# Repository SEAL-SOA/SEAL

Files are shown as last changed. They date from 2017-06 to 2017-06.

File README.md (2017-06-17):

# SEAL
Sistema Embebido para Analisis de Lluvia
El sistema consiste en medir turbiedad y nivel de agua en un tanque, y analizando la calidad del agua, determinar si el agua se destina a riego o a consumo.
Adicionalmente cuenta con una aplicación en Android que lee los valores que envia Arduino por Bluetooth y permite tomar el control de las bombas de agua.

Desarrollado por alumnos de la Universidad Nacional de la Matanza

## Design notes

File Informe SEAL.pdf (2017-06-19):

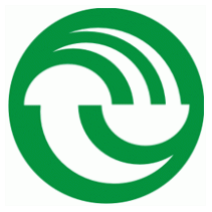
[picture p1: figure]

# UNLaM

# Departamento de Ingeniería e Investigaciones Tecnológicas

# Sistemas Operativos Avanzados

## Internet of Things

## Sistemas Embebidos + Android

# “Sistema Embebido de Análisis de Lluvia”

# SEAL

## 1er cuatrimestre – Año 2017

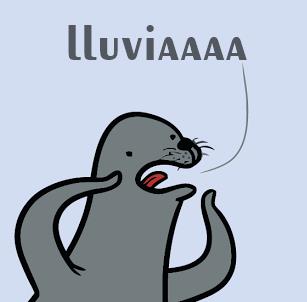
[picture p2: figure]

## Integrantes:

### Coria, Santiago Greco, Maximiliano Minardi, Matías Piemontese, Gerardo

Fecha | Versión | Devolución
19/6/2017 | 1.0

SEAL – Sistema Embebido de Análisis de Lluvia

## Contenido

## 1. Objetivos del Trabajo Práctico

Desarrollar los conocimientos y experiencias adoptados en la cursada acerca de Sistemas Embebidos, IoT y Android con el fin de implementar un sistema capaz de medir la turbiedad del agua de lluvia y determinar en base a las partículas suspendidas en el agua, si la misma es apta para consumo o es destinada para riego.

## 1. Entorno de Trabajo

## 1.1 Hardware

### 1.1.1 Sistema Embebido

- Notebook Lenovo G580 (Intel Core i5 – 4 GB RAM – Windows 10)
- Arduino Mega 2560
- Cables para la conexión entre placa y sensores
- 1 x Placa de desarrollo
- 1 x Sensor digital de temperatura sumergible DS18B20
- 1 x Sensor digital de ultrasonido HC-SR04
- 1 x Sensor analógico/digital de turbidez DFSEN0189 (usamos el
| modo analógico)
- 1 x LCD Module 20x4
- 1 x Interfaz I2C/SPI para LCD
- 1 x Resistencia 1/4W 4K7 Ohm para sensor de temperatura
- 1 x Módulo bluetooth HC-06
- 1 x Módulo de 2 relés de 5v EARE00102SL
- 2 x Bombas de agua

### 1.1.2 Aplicación Android

- DELL Inspiron (Intel Core i7 -16 GB RAM – Windows 10)
- LG 4 PLUS – Android 6.0.1
- Sensor Acelerómetro
- Sensor de Luz
- Vibrador del dispositivo

## 1.2 Software 1.2.1 Sistema Embebido

- Arduino IDE 1.8.2
- Windows 10 Home Single Language x64

## 1.2.2 Aplicación Android

- Android Studio versión 2.3.2

## 2. Alcance del Sistema

## 2.1 Sistema Embebido

2.1.1 | El sistema embebido debe realizar las siguientes
| mediciones: ▪ Turbiedad del agua en base a las partículas suspendidas ▪ Temperatura del agua ▪ Nivel/Volumen de agua en litros.
2.1.2 | El sistema embebido debe enviar constantemente las
| mediciones realizadas por medio de la conexión bluetooth hacia la aplicación Android y también mostrar dichos valores en la pantalla LCD.
2.1.3 | El sistema embebido debe contemplar niveles máximos
| y mínimos de agua para que el nivel de agua no supere el máximo de 3,8 litros ni sea menor a 1,2 litros y el agua quede por debajo de las bombas de drenaje.
2.1.4 | El sistema embebido debe analizar la turbiedad del
| agua cuando el nivel de la misma supere 3,8 litros.
2.1.5 | El sistema debe realizar el drenaje del agua luego de
| analizar la turbiedad de la misma hasta llegar a un nivel tope de 1,2 litros.
2.1.6 | El sistema embebido debe decidir qué bomba encender
| en base a la turbiedad del agua. Si la turbiedad es menor o igual a 2 NTU se debe encender la bomba correspondiente a “Agua para Consumo”. Si la turbiedad es mayor a 2 NTU se debe encender la bomba correspondiente a “Agua para Riego”.
2.1.7 | El sistema embebido debe enviar constantemente, la
| información obtenida por medio de los sensores, a la aplicación por medio de una conexión bluetooth.
2.1.8 | El sistema embebido debe reaccionar ante las
| instrucciones enviadas por medio de la aplicación.
2.1.9 | El sistema embebido debe admitir dos modos de
| operación (automático y manual) determinado por el usuario de la aplicación.

### 2.1.10 El sistema embebido debe hacer parpadear el display

| LCD al momento de recibir una señal especifica de la aplicación Android.

## 2.2 Aplicación Android

2.2.1 | La aplicación Android debe recibir los valores enviado
| por el sistema embebido, de temperatura, turbiedad y ultrasonido por medio de una conexión bluetooth y mostrarlo constantemente por medio de la interfaz.
2.2.2 | La aplicación Android debe permitir cambiar el modo
| de operación del sistema embebido pudiendo elegir entre el modo manual y el modo automático.

### - Modo Automático: El sistema embebido lee

| constantemente el nivel de agua. Al llegar a la cantidad de 3,8 litros, el sistema embebido analiza la turbiedad y decide si destina el agua a riego o a consumo abriendo una u otra bomba, pudiendo así drenar el tanque principal hasta un nivel mínimo de 1.2 litros para no quedar por debajo de las bombas de drenaje.

### - Modo Manual: Al estar en modo manual, el drenaje

| de las bombas se realizará en base a lo que seleccione el usuario por medio de la aplicación. El mismo tendrá la opción de abrir la bomba destinada a agua para consumo o aquella destinada para riego independientemente de la turbiedad del agua. Si bien el control será manual el sistema tendrá un corte automático para que el agua no quede en un nivel por debajo de las bombas y dañe el sistema.
2.2.3 | La aplicación Android debe implementar el sensor
| acelerómetro para determinar qué bomba se debe encender en base a la inclinación hacia la izquierda (bomba de riego) o derecha (bomba de consumo) del dispositivo.
2.2.4 | La aplicación Android debe accionar el vibrador del
| dispositivo en caso que se accione una u otra bomba de drenaje y el modo de operación sea manual.
2.2.5 | La aplicación Android debe enviar una señal al sistema
| embebido cuando detecte un nivel de luz menor al 3 lumenes.

## 3. Diagrama General del Sistema

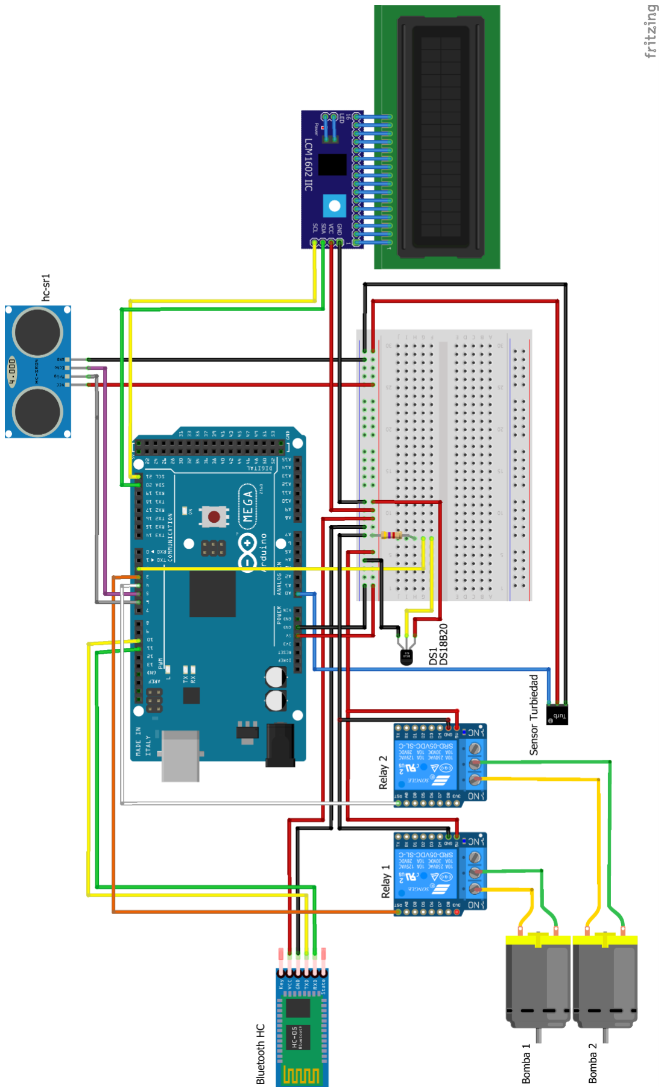
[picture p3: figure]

### El sensor principal de nuestro proyecto es el sensor de TURBIEDAD el

cual posee un switch para cambiar de modo analógico a digital o viceversa.

### Este sensor utiliza la luz para detectar partículas en suspensión en el agua

### mediante la medición de la transmitancia de luz y la velocidad, que cambia con la cantidad de sólidos suspendidos totales (SST) en el agua. A medida

que aumenta el SST, aumenta el nivel de turbidez.

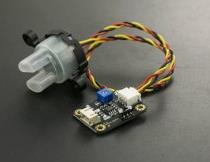
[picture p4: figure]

### Luego en base a las SST devueltos el sensor devuelve un valor que varia entre 0 a 1023. Se debe calcular el voltaje correspondiente a dicha medición mediante la siguiente fórmula:

### Voltaje = SST x (

5.0
1024)

### Una vez obtenido el voltaje se calcula los NTU (Unidad Nefelometrica de Turbidez) equivalentes mediante la siguiente fórmula:

### NTU = −1120.4 x Voltaje + 5742.3 x Voltaje − 4352.9

Si bien esa es la forma que indica el fabricante para calcular los NTU del agua, cuando realizamos las pruebas del sensor, obtuvimos valores fuera de dichos márgenes. Sumado a esto, las mediciones tomadas se veían afectadas a condiciones externas como por ejemplo la luz ambiental. Por lo cual, decidimos adaptar dicho sensor para que se vea afectado lo mínimo posible por estas condiciones colocándole un capuchón que disminuya la

incidencia de la luz.

### Luego de estas modificaciones, realizamos nuevas mediciones y adoptamos el siguiente criterio para obtener los valores de turbiedad en NTU:

Valor informado por el Sensor (VS) | Valor correspondiente a NTU | Informe del Agua
VS >= 780 | 1 | Apta para consumo
760 <= VS < 780 | 1.5 | Apta para consumo
745 <= VS < 760 | 2 | Apta para consumo
VS < 745 | -(166/15) x VS + (24740/3) | Disponible para Riego

## 4. Implementación

## 4.1 Sistema Embebido

4.1.1 Display LCD Para la implementación del LCD se deben agregar las librerías Wire.h y LiquidCrystal_I2C.h para la utilización de la interfaz

I2C. Una vez realizado esto declaramos los parámetros de escritura del LCD de la siguiente manera: LiquidCrystal_I2C lcd(0x27,20,4);
Finalmente inicializamos el LCD y encendemos el backlight mediante las funciones lcd.init() y lcd.backlight().
De esta manera el LCD queda disponible para escribir por pantalla mediante las funciones lcd.setCursor() y lcd.print()

4.1.2 Sensor de temperatura sumergible Para la implementación del sensor de temperatura se deben agregar las librerías OneWire.h y DallasTemperature.h. Luego debemos declarar el PIN utilizado para dicho sensor (nosotros utilizamos el pin digital 2) y finalmente declaramos el bus para la comunicación OneWire, instanciamos la biblioteca DallasTemperature e inicializamos el sensor mediante le siguiente código: OneWire ourWire(pinTemp); DallasTemperature sensorTempSumerg(&ourWire); sensorTempSumerg.begin(); Finalmente obtenemos el valor de la temperatura mediante las siguientes llamadas a funciones: sensorTempSumerg.requestTemperatures(); sensorTempSumerg.getTempCByIndex(0);

## 4.1.3 Sensor de Ultrasonido

Para la implementación del sensor de ultrasonido no se necesitan agregar librerías. Sólo se deben declarar los pines ECHO y TRIGGER. El pin ECHO de entrada determina el tiempo de rebote del ultrasonido y el pin TRIGGER de salida determina el pulso ultrasónico (nosotros utilizamos los pines 5 y 6): pinMode(trigPin,OUTPUT);
pinMode(echoPin,INPUT);

Finalmente calculamos la distancia de la siguiente forma:

digitalWrite(trigPin, LOW);/*Estabilización del sensor*/ delayMicroseconds(2);
digitalWrite(trigPin, HIGH); /*Envío del pulso ultrasónico*/ delayMicroseconds(10);
digitalWrite(trigPin, LOW);
duracion = pulseIn(echoPin,HIGH);/* Función para medir la longitud del pulso entrante. Mide el tiempo que transcurrido entre el
envío del pulso ultrasónico y cuando el sensor recibe el rebote */

distancia = (duracion/(float)2) / 29.1;
capacidad = -0.2656 * distancia + 4.7687;

## 4.1.4 Sensor de Turbiedad

Para la implementación del sensor de turbiedad tampoco es necesario agregar librerías. Simplemente se debe conectar el sensor a una de las entradas analógicas de la placa Arduino y realizar la lectura de dicho pin mediante la siguiente instrucción: int sensorValue = analogRead(A0);

## 4.1.5 Relays para bombas

Para la utilización de los relays no es necesaria incluir librerías, pero se debe declarar los pines utilizados para ambos relays:
int pinRelay1 = 3; | //RELAY 1
int pinRelay2 = 4; | //RELAY 2

Al inicio del proceso, apagamos ambos relays mediante las siguientes instrucciones:
digitalWrite(pinRelay1,HIGH);
digitalWrite(pinRelay2,HIGH);

Finalmente en el proceso se deben abrir y cerrar las bombas mediante las instrucciones digitalWrite(pinRelay,LOW); o digitalWrite(pinRelay, HIGH); respectivamente

## 4.2 Aplicación Android

Al iniciar, la aplicación Android solicita encender el Bluetooth del dispositivo en caso de que el mismo no se encuentre conectado.
En la primera pantalla, el usuario debe seleccionar el Bluetooth dentro de la lista de dispositivos vinculados.

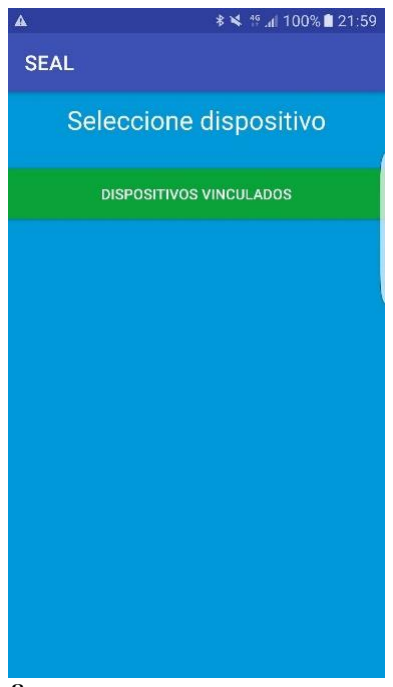
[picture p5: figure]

a

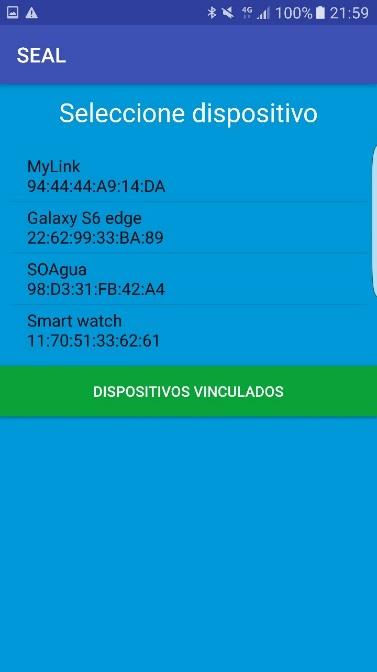
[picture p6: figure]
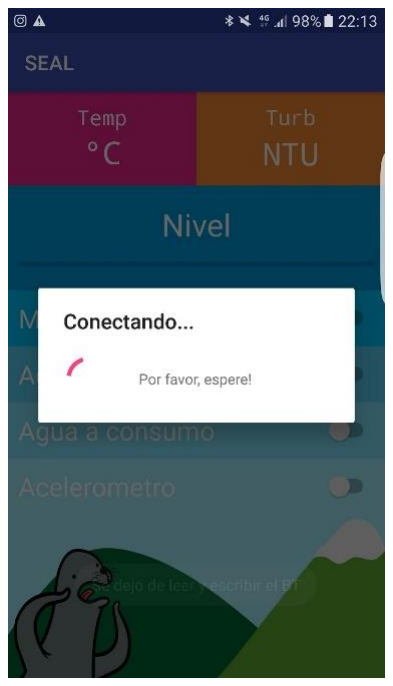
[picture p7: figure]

do, la aplicación Android redirecciona a la pantalla principal donde se visualizan los valores de temperatura, turbiedad y nivel de agua recibidos del sistema embebido. Además, da información sobre el modo de operación, los estados de las bombas de drenaje y la opción para habilitar la funcionalidad del acelerómetro.

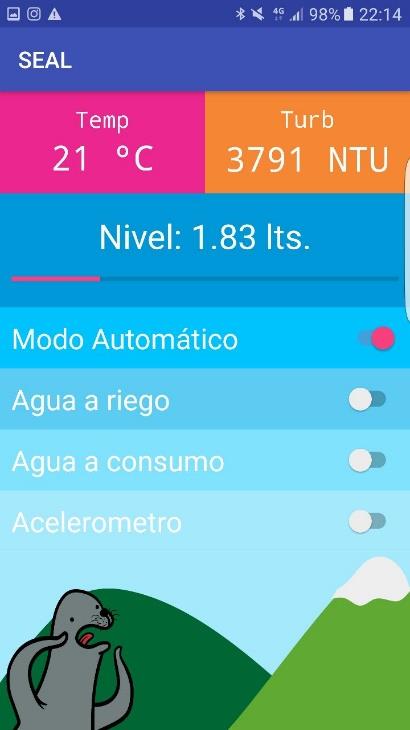
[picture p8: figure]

Al cambiar el modo de operación a Manual, el usuario puede activar las bombas de drenaje si el nivel de agua es superior a 1,2 lts. haciendo click en los switchs o habilitando el sensor acelerómetro y luego, desplazando el celular de izquierda a derecha.

En cambio, el modo de operación Automático, únicamente permite la visualización de los valores e impide al usuario activar las bombas.

## 5. Comunicación Bluetooth

## 5.1 Arduino a Android

Para la utilización del bluetooth se debe incluir la siguiente librería: #include <SoftwareSerial.h>
Luego declaramos los pines RX y TX donde conectamos el modulo HC-06 a la placa Arduino, con la siguiente instrucción:
SoftwareSerial BT(10,11);

Luego realizamos la lectura de los valores que enviamos desde el dispositivo Android mediante el siguiente Código: if(BT.available()) // Si llega un dato por el puerto BT se envía al monitor serial
{
msjin = LeerBT();
Serial.print(msjin);
if (msjin.equals("#FA~")){ArdCtl=1;} else if(msjin.equals("#FM~")){ArdCtl=0;} }

Donde LeerBt() es:
String LeerBT(){
String msj;
delay(10); //delay de contingencia, para cargar el buffer //Cargo el buffer en una variable hasta el fin de linea while (BT.available()>0){
msj+= char(BT.read());
}
return msj;
}

Por último, enviamos el string con un determinado formato que luego vamos a parsear y leer desde android mediante la siguiente función:

void EnviarBT(){
String msjout;
String ModoFun;
String EstadoB1;
String EstadoB2;

// Armo la cadena de envío de valores de sensores al Bluetooth if (ArdCtl==1) ModoFun = "FA";
else ModoFun = "FM";
if (encendido1) EstadoB1 = "B11";
else EstadoB1 = "B10";
if (encendido2) EstadoB2 = "B21"; else EstadoB2 = "B20";

msjout = "#SE" + String(capacidad) + "|" + String(temperatura) + "|" + String(ntu) + "|" + ModoFun + "|" + EstadoB1 + "|" + EstadoB2 + "~"; char msjBT[msjout.length()+1]; msjout.toCharArray(msjBT,msjout.length()+1);

//Envio el mensaje al BT
BT.write(msjBT);

}

## 5.2 Android a Arduino

La conexión se realiza por medio de dos clases que extienden de asyntacks. La primera (ConectBT) nos permite establecer la conexión, creando el socket Bluetooth que mantiene vinculado la aplicación Android con el sistema embebido. La segunda (LeerYEscribirBT) nos permite leer los datos recibidos por el Arduino y a través del método OnProgressUpdate(); actualizar el activity principal (valores y controles).

## 5.3 Formato del mensaje de Comunicación

El mensaje de comunicación posee el siguiente formato: #SECAP|TEMP|NTU|FUNC|EB1|EB2~ Donde:
- #SE: Inicio del mensaje
- CAP: Capacidad del tanque principal
- TEMP: Temperatura del agua
- NTU: Turbiedad del agua
- FUNC: Modo de funcionamiento del sistema, el cuál puede ser MANUAL(FM) o AUTOMATICO(FA)
- EB1: Estado de bomba 1, la cual puede estar encendida (B11) o apagada (B10)
- EB2: Estado de bomba 2, la cual puede estar encendida (B21) o apagada (B20)
- ~: Fin del mensaje.

Mensaje Adicional: #BLB~. Dicho mensaje lo utilizamos para hacer parpadear el LCD cuando la cantidad de luz indicada por el sensor de luz es menor a 3.

## 6. Proyecto Terminado

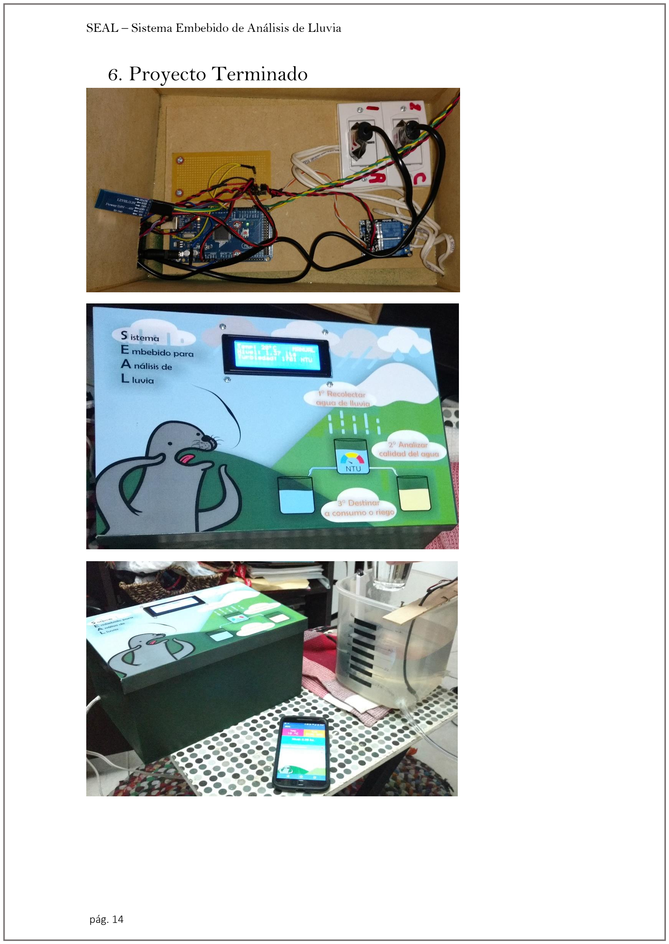
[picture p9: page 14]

## 7. Webgrafía Utilizada

7.1 http://www.didacticaselectronicas.com/index.php/sensores/sensor-turbidez-sen-0189-sen0189-detail
7.2 https://www.arduino.cc/
7.3 https://forum.arduino.cc/index.php?board=32.0
7.4 http://www.lawebdelprogramador.com/foros/Arduino/index1.html 7.5 http://clubarduino.com.ar/index.php?option=com_kunena&view=home&defaultmenu=126&Itemid=124
7.6 https://developer.android.com/
7.7 http://www.sgoliver.net/blog/tareas-en-segundo-plano-en-android-i-thread-y-asynctask/ (http://www.sgoliver.net/blog/tareas-en-segundo-plano-en-android-i-thread-y-asynctask/)
7.8 http://www.androidcurso.com/index.php/tutoriales-android-basico/36-unidad-5-entradas-en-android-teclado-pantalla-tactil-y-sensores/365-ejecutar-una-tarea-en-un-nuevo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 (http://www.androidcurso.com/index.php/tutoriales-android-basico/36-unidad-5-entradas-en-android-teclado-pantalla-tactil-y-sensores/365-ejecutar-una-tarea-en-u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)
7.9 https://es.stackoverflow.com/

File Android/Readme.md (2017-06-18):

Este es el proyecto Android de la aplicación SEAL

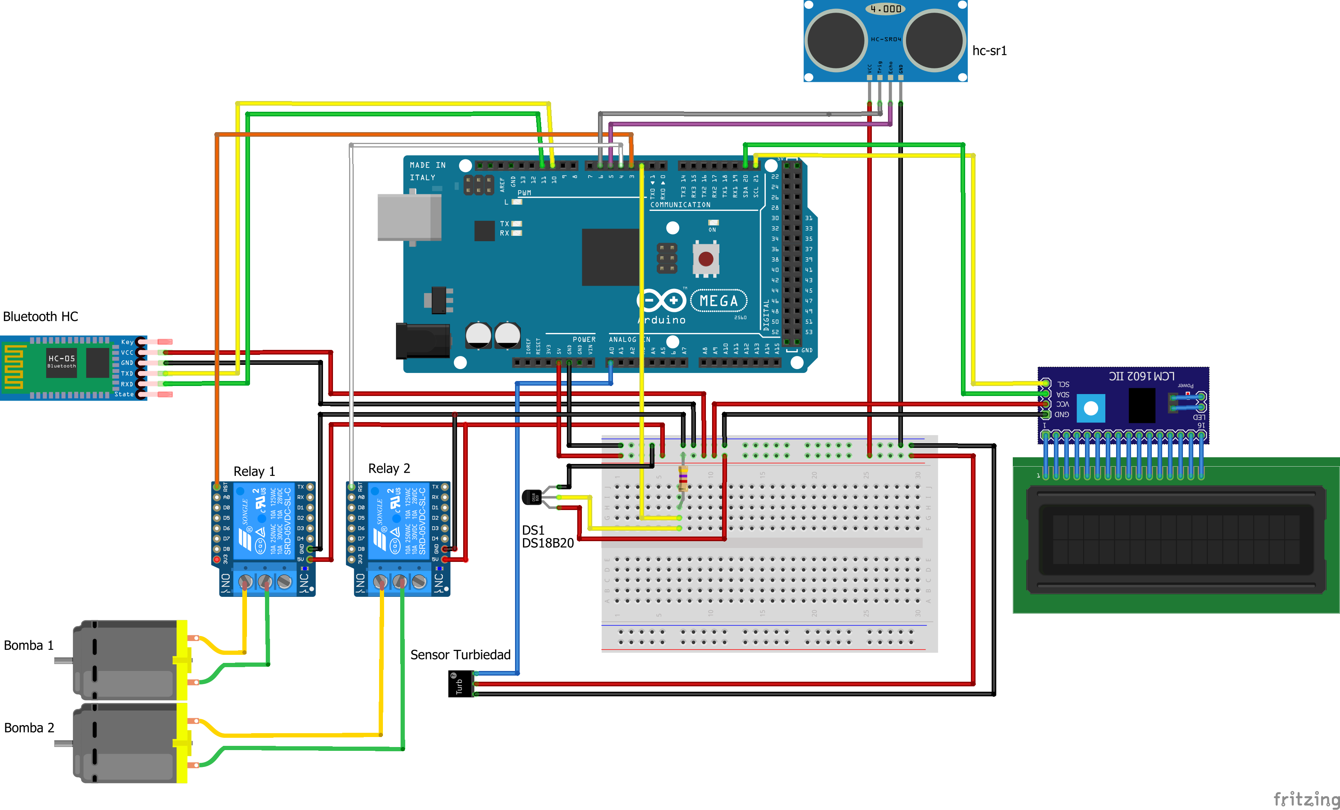
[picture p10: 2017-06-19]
Arduino/Sensor_Calidad_Agua_bb.png

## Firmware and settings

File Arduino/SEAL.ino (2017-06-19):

//Bibliotecas
#include <Wire.h>              //LCD
#include <LiquidCrystal_I2C.h> //LCD
#include <OneWire.h>           //Sensor de temperatura
#include <DallasTemperature.h> //Sensor de temperatura
#include <SoftwareSerial.h>    //SoftwareSerial para Bluetooth

#define MSGSTR #
#define MSGEND ~
#define SPLIT  | 

//Declaro los pines utilizados para los sensores
int pinTemp   = 2;       //SENSOR DE TEMPERATURA
int pinRelay1 = 3;       //RELAY 1
int pinRelay2 = 4;       //RELAY 2
int echoPin   = 5;       //SENSOR DE ULTRASONIDO - ECHO
int trigPin   = 6;       //SENSOR DE ULTRASONIDO - TRIGGER
SoftwareSerial BT(10,11);// Pines RX y TX del Arduino conectados al Bluetooth

//Declaro los parametros de escritura del LCD
LiquidCrystal_I2C  lcd(0x27,20,4); // 0x27 is the I2C bus address for an unmodified backpack

//Temperatura
OneWire ourWire(pinTemp);                     //Bus para comunicación OneWire (Temperatura)
DallasTemperature sensorTempSumerg(&ourWire); //Se instancia la biblioteca DallasTemperature

//Variables para controlar las bombas de agua
bool encendido1;
bool encendido2;

//Varible de modo de funcionamiento
int ArdCtl=1;

//Variables para lectura de sensores
float capacidad;
int ntu;
int temperatura;

/*---------------------*\
| SETUP                 |
|      Inicializaciones |
\*---------------------*/
void setup() {
  //Inicializamos el Monitor Serie
  Serial.begin (9600);

  //Inicializo variables para controlar las bombas de agua
  encendido1 = false;
  encendido2 = false;

  //Declaramos los pines para el sensor de ultrasonido
  pinMode(trigPin,OUTPUT);
  pinMode(echoPin,INPUT);

  //Se inicializa el sensor de Temperatura Sumergible
  sensorTempSumerg.begin(); 

  //Inicializamos el LCD y encendemos el Backlight
  lcd.init();
  lcd.backlight();
  
  //Declaramos los pines para los relay 1 y 2
  pinMode(pinRelay1,OUTPUT);
  pinMode(pinRelay2,OUTPUT);
  //Al comienzo apagamos ambos relays
  digitalWrite(pinRelay1,HIGH);
  digitalWrite(pinRelay2,HIGH);

  //Inicializamos el puerto serie BT que hemos creado
  BT.begin(9600);

}


/*----------------------------*\
| LOOP:                        |
|      Comportamiento principal|
\*----------------------------*/
void loop() {
  
  //Declaracion de variables locales
  char buffer[64];
  String msjin;
  int i;
  //Leo capacidad
  capacidad = CalcularCapacidad();

  //Leo Nivel de Turbiedad
  ntu = CalcularTurbiedad();

  //Leo Temperatura del Agua
  temperatura = CalcularTemperaturaAgua();
  //Eliminamos todos los caracteres del LCD
  lcd.clear();

//Por proteccion se apagan las bombas al llegar al minimo nivel habilitado
  if (capacidad <= 1.2)
      { if (encendido1) {digitalWrite(pinRelay1,HIGH);
                         encendido1=false;}
        if (encendido2) {digitalWrite(pinRelay2,HIGH);
                         encendido2=false;}
        lcd.setCursor(0,3);       
        lcd.print("Nivel limite");
       }

  //Leemos que nos envia el bluetooth
  if(BT.available())    // Si llega un dato por el puerto BT se envía al monitor serial
  {
    msjin = LeerBT();
    Serial.print(msjin);
    if (msjin.equals("#FA~")){ArdCtl=1;}
    else if(msjin.equals("#FM~")){ArdCtl=0;}
  }

  //Informo el estado por Bluetooth
  EnviarBT();


  //Seteamos el cursor en la 1º linea
  lcd.setCursor(0,0);       
  lcd.print("Temp: ");
  lcd.print(temperatura);
  lcd.print(char(223));
  lcd.print("C");

  //Verifica el estado de funcionamiento
  if (ArdCtl == 0){lcd.setCursor(14,0);
                   lcd.print("MANUAL");}
  else {lcd.setCursor(14,0);
        lcd.print("AUTO");}

  //Seteamos el cursor en la 2º linea
  lcd.setCursor(0,1);
  lcd.print("Nivel: "  );
  lcd.print(capacidad);
  lcd.print(" lts");
  
  //Seteamos el cursor en la 3º linea
  lcd.setCursor(0,2);
  lcd.print("Turbiedad: ");
  lcd.print(ntu);
  lcd.print(" NTU");

if (ArdCtl == 1){
  //Modo autonomo

        //Si llega al punto máximo de agua
          if (capacidad > 3.8)
          {
            if (ntu <= 2)
             {//Agua para consumo, encendemos Relay de Bomba 1
              digitalWrite(pinRelay1,LOW);
              encendido1 = true;
              lcd.setCursor(0,3);
              lcd.print("Agua a consumo");
             }
            else
             {
              digitalWrite(pinRelay2,LOW);
              encendido2 = true;
              lcd.setCursor(0,3);
              lcd.print("Agua a riego");
             }

           //Informo el estado por Bluetooth
           EnviarBT();

            //Mantenemos la bomba encendida hasta que el agua baje
            while (capacidad > 1.2)
                    {capacidad = CalcularCapacidad();
                     lcd.setCursor(0,1);       
                     lcd.print("Nivel: "  );
                     lcd.print(capacidad);
                     lcd.print(" lts");
                     delay(400);
                     }

          }
    }//ArdCtl = 0
     //Modo manual
    else
      {if (msjin.equals("#B11~")&&capacidad > 1.2) {//Abrir bomba 1
                                                    digitalWrite(pinRelay1,LOW);
                                                    encendido1 = true;
                                                    lcd.setCursor(0,3);
                                                    lcd.print("Agua a consumo");
                                                    }
       else if(msjin.equals("#B10~")){//Cerrar bomba 1
                              digitalWrite(pinRelay1,HIGH);
                              encendido1 = false;
                              lcd.setCursor(0,3);
                              lcd.print("Consumo cerrada");
                              }
       else if(msjin.equals("#B21~")&&capacidad > 1.2){//Abrir bomba 2
                                                       digitalWrite(pinRelay2,LOW);
                                                       encendido2 = true;
                                                       lcd.setCursor(0,3);
                                                       lcd.print("Agua a riego");}
       else if(msjin.equals("#B20~")){//Cerrar bomba 2
                                digitalWrite(pinRelay2,HIGH);
                                encendido2 = false;
                                lcd.setCursor(0,3);
                                lcd.print("Riego cerrada");}
       else if(msjin.equals("#BLB~")){//Parpadeo de pantalla
                                      lcd.noBacklight();
                                      delay(100);
                                      lcd.backlight();
                                      delay(100);
                                      lcd.noBacklight();
                                      delay(100);
                                      lcd.backlight();}

       //Informo el estado por Bluetooth
       EnviarBT();
       }
  
  delay(500); 
}


/*------------------------------------*\
| CalcularCapacidad:                   |
|      Retorna nivel del agua en litros|
\*------------------------------------*/
float CalcularCapacidad(){
  float duracion;
  float distancia;
  float capacidad;
  
  digitalWrite(trigPin, LOW);
  delayMicroseconds(2);
  digitalWrite(trigPin, HIGH);
  delayMicroseconds(10);
  digitalWrite(trigPin, LOW);

  duracion = pulseIn(echoPin,HIGH);
  distancia = (duracion/(float)2) / 29.1;

  capacidad = -0.2656 * distancia + 4.7687;
  
  return capacidad;
  }


/*----------------------------*\
| CalcularTemperaturaAgua:     |
|      Retorna temp del sensor |
\*----------------------------*/
int CalcularTemperaturaAgua(){
  //Prepara el sensor para la lectura
  sensorTempSumerg.requestTemperatures(); 
  return int(sensorTempSumerg.getTempCByIndex(0));
}


/*---------------------------------*\
| CalcularTurbiedad:                |
|      Calcula la turbiedad en "NTU"|
\*---------------------------------*/
int CalcularTurbiedad(){
  //Leemos el pin 0 analógico y obtenemos un valor entre 0 y 1023 
  //Cuanto mas chico sea el valor (particulas suspendidas en el agua) mayor turbidez
  int NTU=0;
  int sensorValue = analogRead(A0);

  if (sensorValue >= 780) NTU = 1;
  else if (780 > sensorValue && sensorValue >= 760 )  NTU = 1.5;
  else if (760 > sensorValue && sensorValue >= 745 )  NTU = 2;
  else if (745 > sensorValue )  NTU =-(166/15)* sensorValue +(24740/3);

  return NTU;  
}

/*---------------------------------*\
| Leer Bluetooth:                   |
|      Lee lo recibido por Bluetooth|
\*---------------------------------*/
String LeerBT(){
  String msj;

  delay(10); //delay de contingencia, para cargar el buffer

//Cargo el buffer en una variable hasta el fin de linea
  while (BT.available()>0){
                    msj+= char(BT.read()); 
                    }

  return msj;
}


/*---------------------------------*\
| Enviar Bluetooth:                 |
|      Envia al Bluetooth lo        |
|      recibido por parametro.      |
\*---------------------------------*/
void EnviarBT(){
  String msjout;
  String ModoFun;
  String EstadoB1;
  String EstadoB2;

  // Armo la cadena de envío de valores de sensores al Bluetooth
  if (ArdCtl==1) ModoFun = "FA";
     else ModoFun = "FM";
  if (encendido1) EstadoB1 = "B11";
     else EstadoB1 = "B10";
  if (encendido2) EstadoB2 = "B21";
     else EstadoB2 = "B20";
  
  msjout = "#SE" + String(capacidad) + "|" + String(temperatura) + "|" + String(ntu) + "|" + ModoFun + "|" + EstadoB1 + "|" + EstadoB2 + "~";
  char msjBT[msjout.length()+1];
  msjout.toCharArray(msjBT,msjout.length()+1);
  
  //Envio el mensaje al BT
  BT.write(msjBT);

}
